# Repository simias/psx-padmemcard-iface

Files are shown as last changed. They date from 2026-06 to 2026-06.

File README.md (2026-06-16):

# ATmega4809-based interface for PlayStation Memory Cards and Controllers

This repository contains the schematics and controller code to create a simple
UART-based interface to PlayStation Memory Card and Controllers.

The design uses a simple ATmega4809 microcontroller running at 4MHz.

The PlayStation Pad/MemCard connector uses both 3.5V (for all communication
signals) and 7.5V (mainly used for DualShock rumble motors and other
power-hungry features). I think that most devices will work perfectly fine with
only the 3.5V input, but in order to be as close as possible to the real
hardware I power my board with a 7.5V that I can wire to the relevant pin of the
Pad/MemCard port, and I use a cheap off-the-shelf DC-DC module to convert that
7.5V to 3.5V which I use to power the controller.

I also send the 5V from the UART-to-USB and UPDI inputs to the DC-DC input
(through diodes) to allow powering the board from USB, but in this case this
same 5V will be sent to the Pad/MemCards instead of a true 7.5V.

A single LED is pulsed with PWM to show activity.

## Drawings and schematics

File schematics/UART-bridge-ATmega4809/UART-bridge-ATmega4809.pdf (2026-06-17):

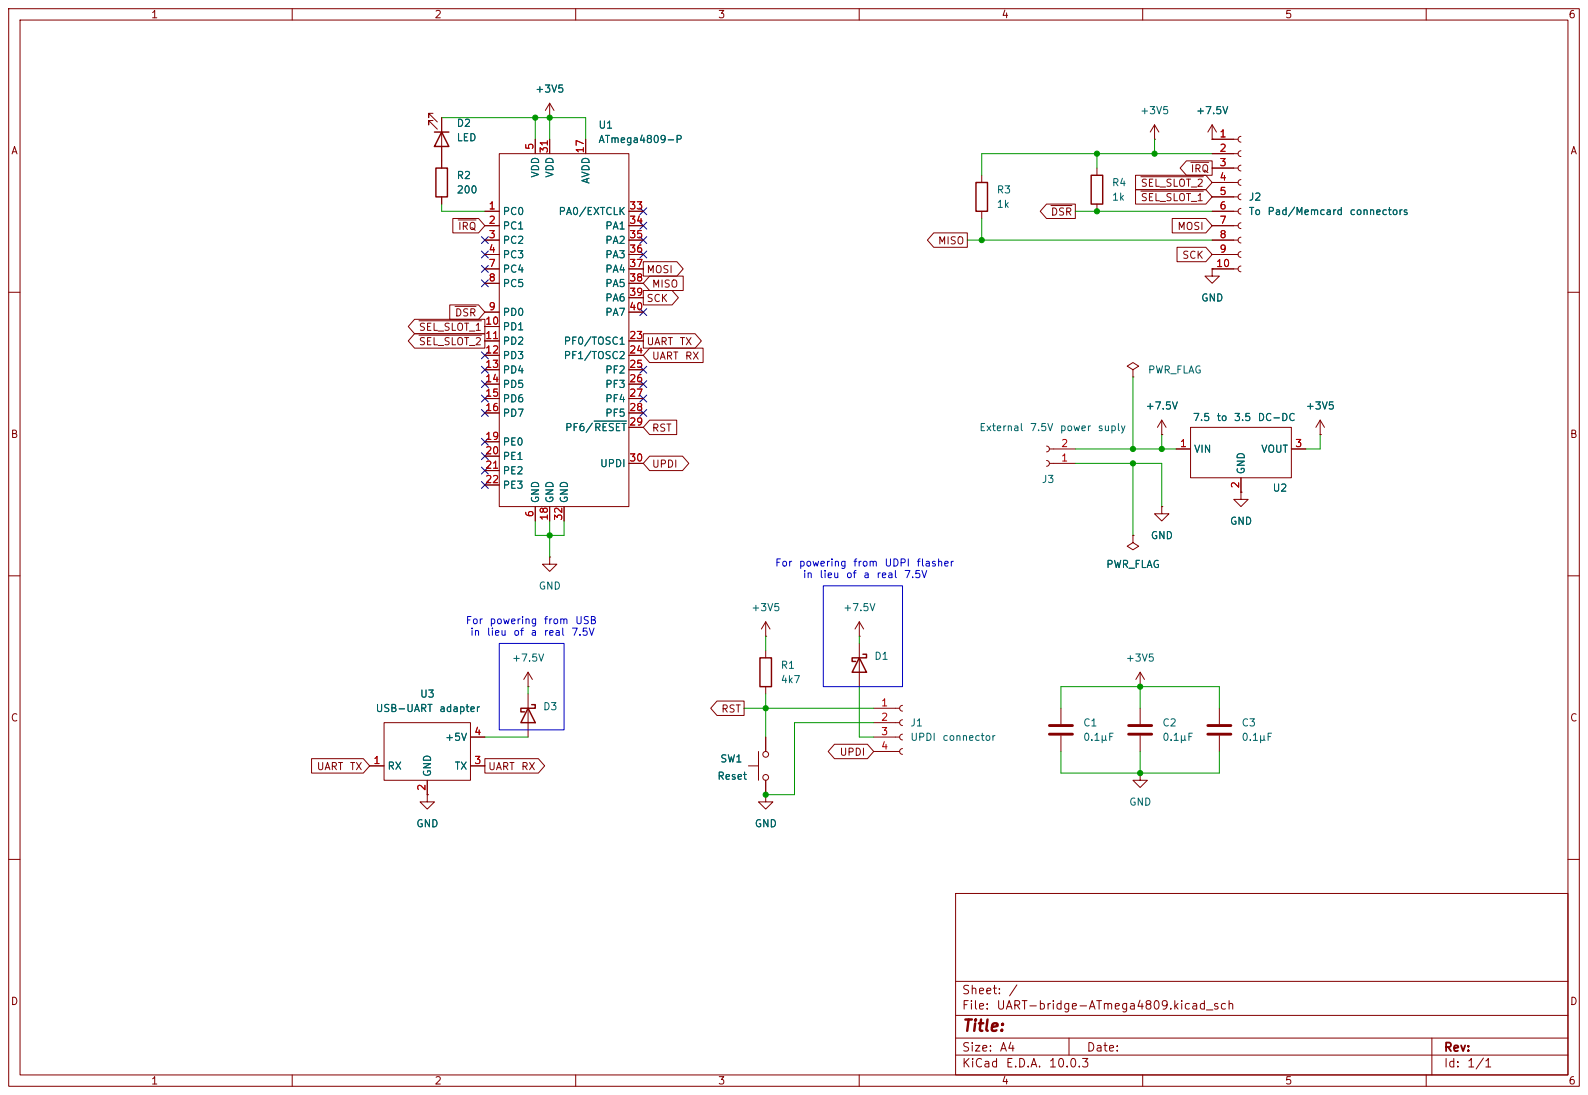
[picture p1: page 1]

in lieu of a real 7.5V U1
ATmega4809-P

6 PC4 7 PC5 8 PD0 9 PD1 10 PD2 11 PD3 12 PD4 13 PD5 14 PD6 15 PD7 16 AVDD 17 GND 18 PE0 19 PE1 20 PE2 21 PE3 22 PF0/TOSC1 23 PF1/TOSC2 24 PF2 25 PF3 26 PF4 27 PF5 28 PF6/RESET 29 UPDI 30 VDD 31 GND 32

SCK UPDI RST UART TX UART RX DSR UART TX

For powering from UDPI flasher

For powering from USB
in lieu of a real 7.5V

Size: A4 | Rev:
KiCad E.D.A. 10.0.3 | Id: 1/1

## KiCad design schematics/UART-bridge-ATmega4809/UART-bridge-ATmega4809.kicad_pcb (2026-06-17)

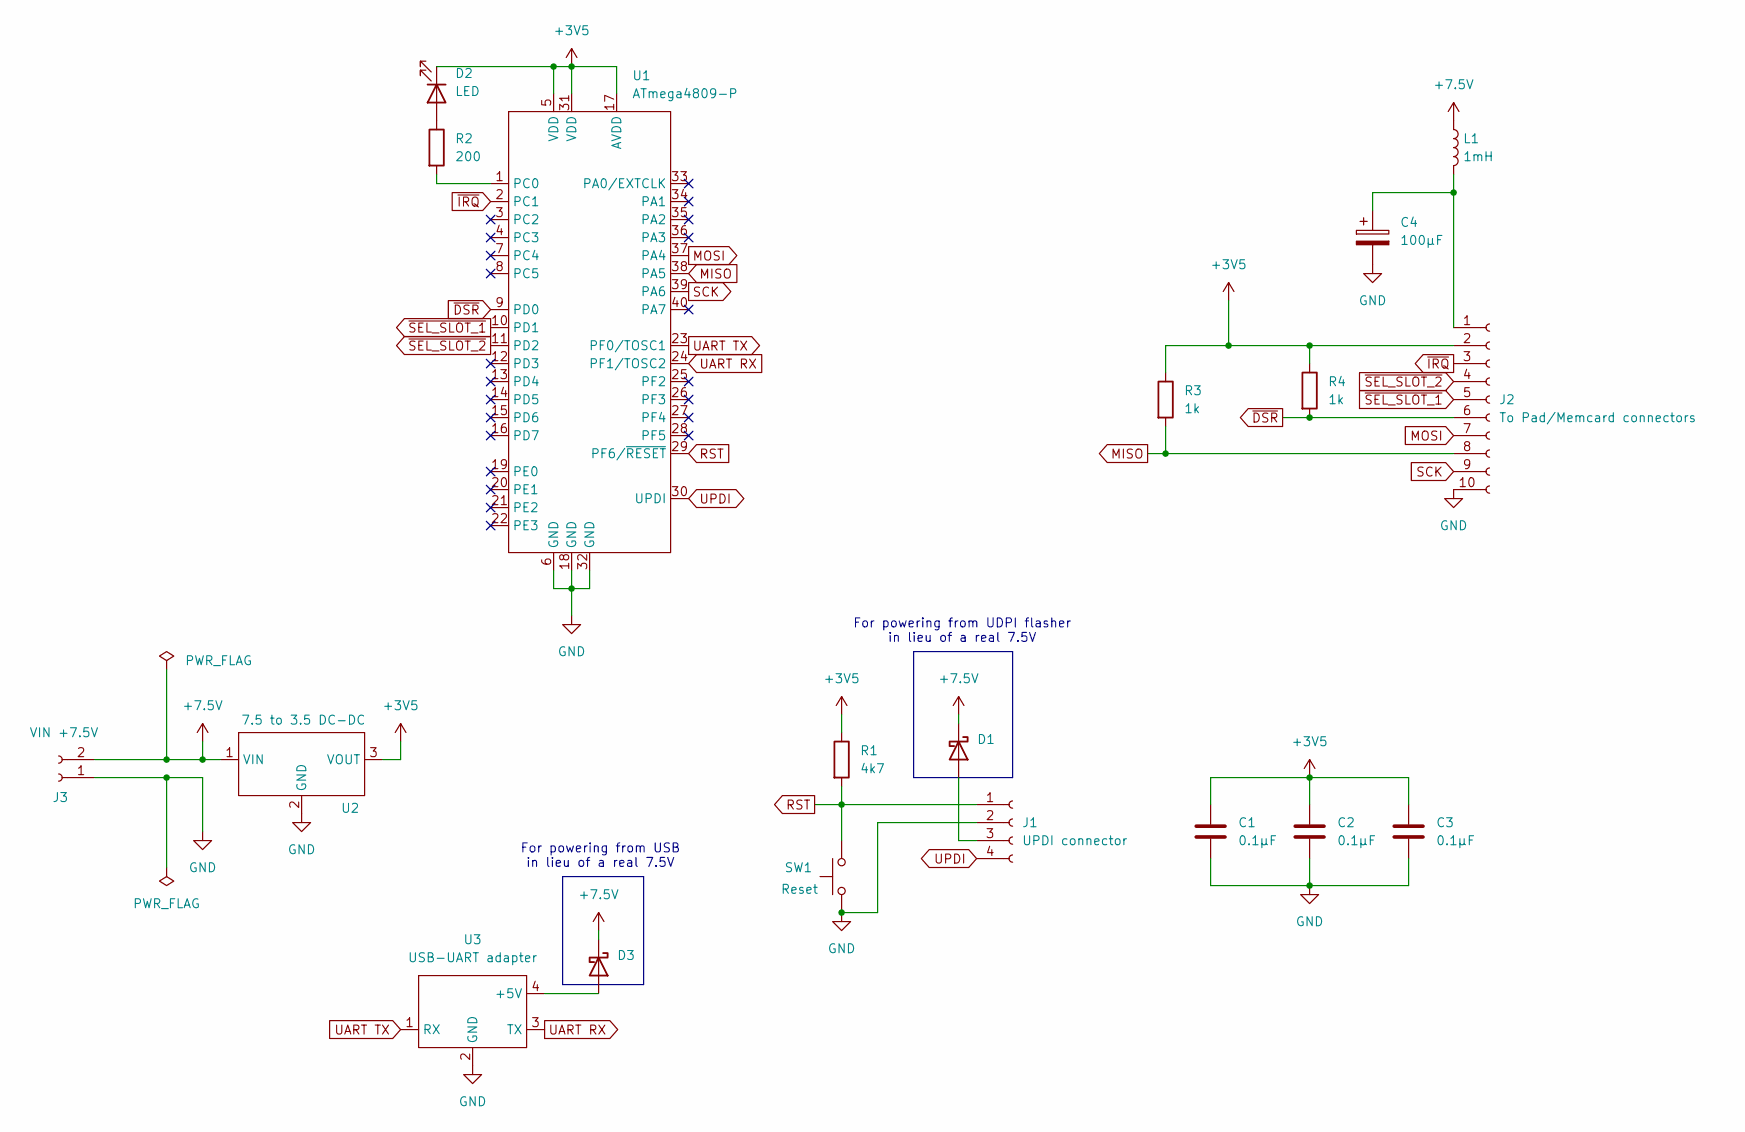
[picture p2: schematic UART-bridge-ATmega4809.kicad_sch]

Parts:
C1, C2, C3: 0.1µF; C_Disc_D5.0mm_W2.5mm_P5.00mm
C4: 100µF; C_Radial_D5.0mm_H11.0mm_P2.00mm
D1, D3: D_Schottky; D_A-405_P7.62mm_Horizontal
D2: LED; LED_D5.0mm_Clear
J1: UPDI connector; PinSocket_1x04_P2.54mm_Vertical
J2: To Pad/Memcard connectors; PinSocket_1x10_P2.54mm_Vertical
J3: VIN +7.5V; PinSocket_1x02_P2.54mm_Vertical
L1: 1mH; L_Radial_D7.0mm_P3.00mm
R1: 4k7; R_Axial_DIN0207_L6.3mm_D2.5mm_P7.62mm_Horizontal
R2: 200; R_Axial_DIN0207_L6.3mm_D2.5mm_P7.62mm_Horizontal
R3, R4: 1k; R_Axial_DIN0207_L6.3mm_D2.5mm_P7.62mm_Horizontal
SW1: Reset; SW_PUSH_6mm
U1: ATmega4809-P; DIP-40_W15.24mm_Socket
U2: 7.5 to 3.5 DC-DC; PinSocket_1x03_P2.54mm_Vertical
U3: USB-UART adapter; PinSocket_1x06_P2.54mm_Vertical

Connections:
+3V5: C1.1, C2.1, C3.1, D2.1 (K), J2.2, R1.1, R3.1, R4.1, U1.5 (VDD), U1.17 (AVDD), U1.31 (VDD), U2.3 (VOUT)
+7.5V: D1.1 (K), D3.1 (K), J3.2, L1.1, U2.1 (VIN)
GND: C1.2, C2.2, C3.2, C4.2, J1.2, J2.10, J3.1, SW1.1, U1.6 (GND), U1.18 (GND), U1.32 (GND), U2.2 (GND), U3.2 (GND)
MISO: J2.8, R3.2, U1.38 (PA5)
MOSI: J2.7, U1.37 (PA4)
unnamed: D1.2 (A), J1.3
unnamed: D2.2 (A), R2.1
unnamed: D3.2 (A), U3.4 (+5V)
unnamed: C4.1, J2.1, L1.2
unnamed: R2.2, U1.1 (PC0)
RST: J1.1, R1.2, SW1.2, U1.29 (PF6/~RESET)
SCK: J2.9, U1.39 (PA6)
UART RX: U1.24 (PF1/TOSC2), U3.3 (TX)
UART TX: U1.23 (PF0/TOSC1), U3.1 (RX)
UPDI: J1.4, U1.30 (UPDI)
~DSR: J2.6, R4.2, U1.9 (PD0)
~IRQ: J2.3, U1.2 (PC1)
~SEL_SLOT_1: J2.5, U1.10 (PD1)
~SEL_SLOT_2: J2.4, U1.11 (PD2)

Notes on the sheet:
For powering from USB in lieu of a real 7.5V
For powering from UDPI flasher in lieu of a real 7.5V

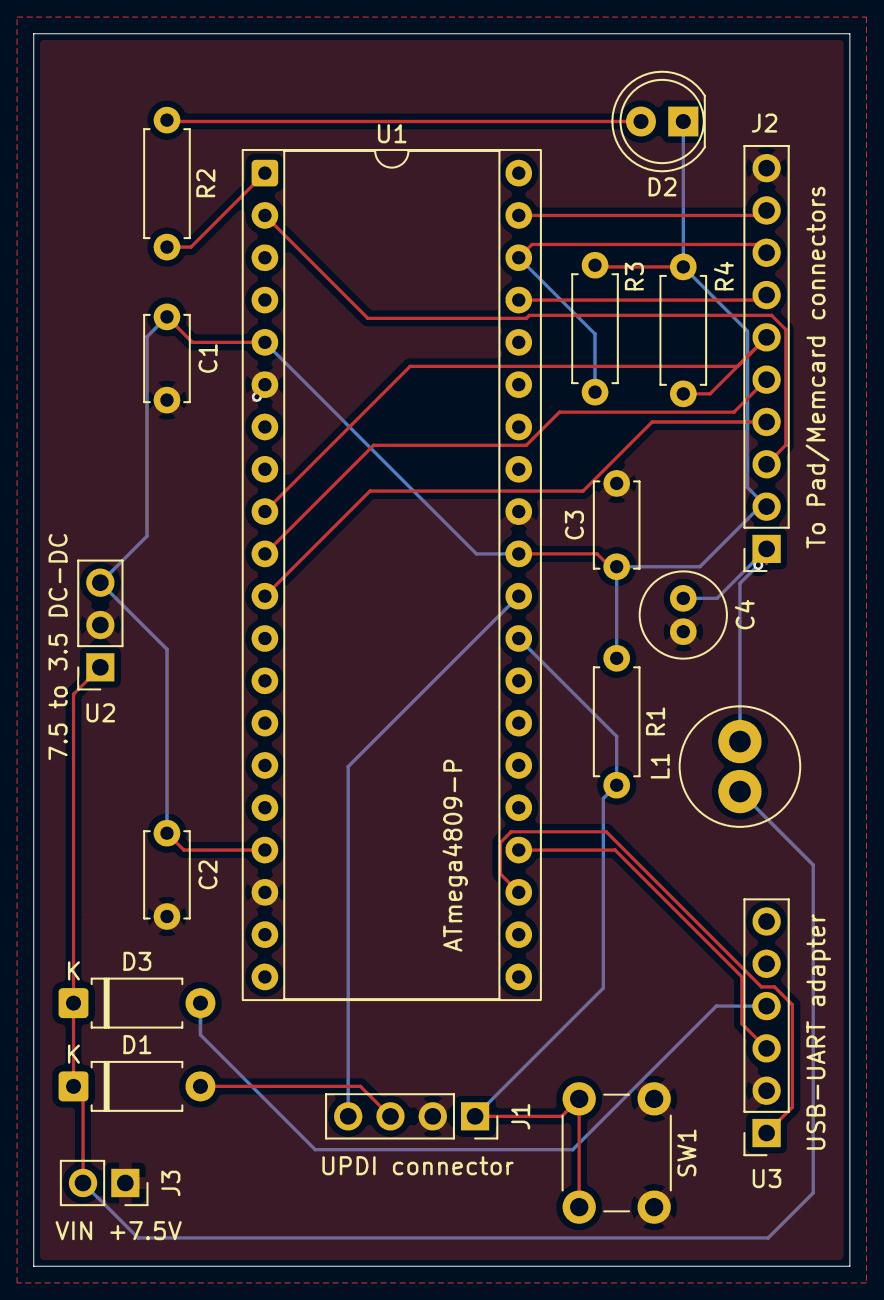
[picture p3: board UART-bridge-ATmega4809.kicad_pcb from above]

Board: 2 copper layers, 49.0 x 74.0 mm, 19 parts (0 on the bottom side), 19 nets.

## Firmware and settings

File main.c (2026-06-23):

#include <avr/interrupt.h>
#include <avr/io.h>
#include <avr/sleep.h>
#include <avr/wdt.h>
#include <stdbool.h>
#include <stdio.h>
#include <util/delay.h>

#define ARRAY_SIZE(_arr) (sizeof(_arr) / sizeof((_arr)[0]))

#define BAUD_RATE 115200
#define USART_BAUD_RATE(_br) ((F_CPU * 4 + (_br) / 2) / (_br))

enum padmem_slot {
    SLOT_1 = 1,
    SLOT_2 = 2,
};

static void spi_init(void)
{
    /* Set MOSI and CLK pins direction to output */
    PORTA.DIR |= PIN4_bm | PIN6_bm;

    /* Pull Up on MISO (warning: needs external 1kohm pull-up, in my tests this
     * internal PU is not sufficient)*/
    PORTA.PIN5CTRL = PORT_PULLUPEN_bm;

    SPI0.CTRLB = SPI_MODE_3_gc | SPI_SSD_bm;

    /* LSB first, CLK_PER / 16 */
    SPI0.CTRLA = SPI_DORD_bm | SPI_ENABLE_bm | SPI_MASTER_bm |
                 SPI_PRESC_DIV16_gc;
}

static uint8_t spi_wait_bsy(void)
{
    for (;;) {
        uint8_t flg = SPI0.INTFLAGS;

        if (flg & SPI_WRCOL_bm) {
            printf("SPI collision!");
            return 0xff;
        }

        if (flg & SPI_IF_bm) {
            return SPI0.DATA;
        }
    }
}

static uint8_t spi_exchange(uint8_t v)
{
    SPI0.DATA = v;
    return spi_wait_bsy();
}

/* Must be a power of two */
#define TX_FIFO_LEN 0x40
#define TX_FIFO_IMASK ((TX_FIFO_LEN << 1) - 1)

static volatile uint8_t uart_tx_fifo[TX_FIFO_LEN];
static volatile uint8_t uart_tx_wi = 0;
static volatile uint8_t uart_tx_ri = 0;

static bool uart_can_write(void)
{
    return USART2.STATUS & USART_DREIF_bm;
}

ISR_N(USART2_DRE_vect_num)
static void uart_tx_irq(void)
{
    uint8_t ri = uart_tx_ri;
    uint8_t wi = uart_tx_wi;

    if (ri != wi && uart_can_write()) {
        USART2.TXDATAL = uart_tx_fifo[(ri++) & (TX_FIFO_LEN - 1)];
        uart_tx_ri = ri & TX_FIFO_IMASK;
    }

    if (ri == wi) {
        /* FIFO empty, disable IRQ */
        USART2.CTRLA &= ~USART_DREIE_bm;
    }
}

static void uart_putchar(int c)
{
    uint8_t sr = SREG;
    uint8_t ri;
    uint8_t wi;

    cli();

    ri = uart_tx_ri;
    wi = uart_tx_wi;

    if (ri == wi && uart_can_write()) {
        /* FIFO is empty and UART can accept a byte, just use that */
        USART2.TXDATAL = c;
        goto done;
    }

    /* UART is busy, attempt to store in the buffer */
    while ((wi ^ TX_FIFO_LEN) == ri) {
        /* Buffer full! */
        if (!(sr & CPU_I_bm)) {
            /* Interrupts were disabled when we were called, we can't sleep, so
             * we give up. */
            goto done;
        }

        /* Wait for UART to empty */
        sei();
        sleep_cpu();
        cli();

        ri = uart_tx_ri;
        wi = uart_tx_wi;
    }

    uart_tx_fifo[(wi++) & (TX_FIFO_LEN - 1)] = c;

    uart_tx_wi = wi & TX_FIFO_IMASK;

    USART2.CTRLA |= USART_DREIE_bm;

done:
    SREG = sr;
}

static int uart_putchar_stream(char c, FILE *stream)
{
    (void)stream;

    if (c == '\n') {
        uart_putchar('\r');
    }

    uart_putchar(c);

    return c;
}

static FILE uart_stream =
    FDEV_SETUP_STREAM(uart_putchar_stream, NULL, _FDEV_SETUP_WRITE);

static void uart_tx_frame(uint8_t cmd, const uint8_t *dat, uint8_t len)
{
    uint8_t csum = cmd;
    uint8_t i;

    uart_putchar(0xa6);
    uart_putchar(cmd);

    for (i = 0; i < len; i++) {
        uint8_t b = dat[i];
        csum += b;
        uart_putchar(b);
        if (b == 0xa7) {
            /* Escape */
            uart_putchar(b);
        }
    }

    uart_putchar(0xa7);
    uart_putchar((len + 1) & 0x7f);
    uart_putchar(csum ^ 0xff);
}

static void uart_tx_nack(void)
{
    uart_tx_frame('!', NULL, 0);
}

enum uart_rx_state {
    RX_START,
    WAIT_FOR_DATA,
    WAIT_FOR_ESCAPE,
    WAIT_FOR_CSUM,
    RX_DONE,
};

static volatile enum uart_rx_state uart_st = RX_START;
static volatile uint8_t rx_buf[256];
static volatile uint8_t rx_buf_len;

ISR_N(USART2_RXC_vect_num)
static void uart_rx_irq(void)
{
    uint8_t b = USART2.RXDATAL;
    enum uart_rx_state nstate = RX_START;
    /* How many bytes to receive - 1*/
    static uint8_t csum;
    static uint8_t wi;

    switch (uart_st) {
    case RX_START:
        if (b == 0xa5) {
            wi = 0;
            csum = 0;
            nstate = WAIT_FOR_DATA;
        }
        break;

    case WAIT_FOR_DATA:
        if (b == 0xa7) {
            nstate = WAIT_FOR_ESCAPE;
        } else {
            rx_buf[wi++] = b;
            csum += b;
            nstate = WAIT_FOR_DATA;

            if (wi == 0) {
                /* Overflow */
                nstate = RX_START;
            }
        }

        break;

    case WAIT_FOR_ESCAPE:
        if (b == 0xa7) {
            /* 0xa7 0xa7 -> we want an 0xa7 */
            rx_buf[wi++] = b;
            csum += b;
            nstate = WAIT_FOR_DATA;

            if (wi == 0) {
                /* Overflow */
                nstate = RX_START;
            }
        } else if ((b >> 4) == 0xb) {
            /* 0-RLE
             *
             * We could use a more aggressive encoding allowing for even longer
             * runs, but eventually the decoding takes too long and we miss the
             * next byte. Plus the gains become really small.
             */
            uint8_t nzero = (b & 0xf) + 3;
            uint8_t wi_s = wi;

            nstate = WAIT_FOR_DATA;

            while (nzero--) {
                rx_buf[wi++] = 0;
            }

            if (wi < wi_s) {
                /* Overflow */
                nstate = RX_START;
            }
        } else if (b == (wi & 0x7f)) {
            /* End of data */
            nstate = WAIT_FOR_CSUM;
        } else {
            /* Spurious/corrupted data */
            uart_tx_nack();
            nstate = RX_START;
        }

        break;

    case WAIT_FOR_CSUM:
        if ((csum ^ 0xff) == b) {
            rx_buf_len = wi;
            nstate = RX_DONE;
        } else {
            uart_tx_nack();
        }
        break;

    case RX_DONE:
        if (wi > 0) {
            nstate = RX_DONE;
        } else {
            nstate = RX_START;
        }
        break;
    }

    if (nstate != RX_START && nstate != RX_DONE) {
        TCA0.SINGLE.CMP0BUF = 0x20;
    }

    uart_st = nstate;
}

static void uart_init(void)
{
    /* Add pull-up on RX pin for when nothing is connected */
    PORTF.PIN1CTRL = PORT_PULLUPEN_bm;

    /* PIN F1 TX*/
    PORTF.DIR |= PIN0_bm;

    USART2.BAUD = USART_BAUD_RATE(BAUD_RATE);
    USART2.CTRLA = USART_RXCIE_bm;
    USART2.CTRLB = USART_TXEN_bm | USART_RXEN_bm;

    stdout = &uart_stream;
}

static void pwm_init(void)
{
    /* LED on PC0: use PWM */
    PORTC.DIR |= PIN0_bm;

    PORTMUX.TCAROUTEA &= ~PORTMUX_TCA0_gm;
    PORTMUX.TCAROUTEA |= PORTMUX_TCA0_PORTC_gc;

    /* Period */
    TCA0.SINGLE.PER = 0xff;

    /* Duty cycle */
    TCA0.SINGLE.CMP0 = 0x10;

    TCA0.SINGLE.CTRLB = TCA_SINGLE_CMP0EN_bm | TCA_SINGLE_WGMODE_SINGLESLOPE_gc;

    /* Set divider */
    TCA0.SINGLE.CTRLA = TCA_SINGLE_CLKSEL_DIV2_gc | TCA_SINGLE_ENABLE_bm;
}

static void rtc_waitbsy(void)
{
    while (RTC.STATUS & (RTC_CTRLABUSY_bm | RTC_CNTBUSY_bm | RTC_PERBUSY_bm |
                         RTC_CMPBUSY_bm)) {
        ;
    }
}

static volatile uint8_t nticks_10ms = 0;

ISR_N(RTC_CNT_vect_num)
static void rtc_irq(void)
{
    uint8_t pwm_cmp;

    /* ACK */
    RTC.INTFLAGS = RTC_OVF_bm;

    nticks_10ms++;

    pwm_cmp = TCA0.SINGLE.CMP0BUFL;

    if (pwm_cmp > 10) {
        pwm_cmp -= 2;

        TCA0.SINGLE.CMP0BUFL = pwm_cmp;
        TCA0.SINGLE.CMP0BUFH = 0;
    }
}

static void rtc_init(void)
{
    /* We want a tic every 10ms */
    rtc_waitbsy();
    RTC.PER = (32768 + (100 >> 1)) / 100;

    rtc_waitbsy();
    RTC.CLKSEL = RTC_CLKSEL_INT32K_gc;

    /* Enable overflow IRQ */
    rtc_waitbsy();
    RTC.INTCTRL = RTC_OVF_bm;

    /* Enable RTC with no prescaling */
    rtc_waitbsy();
    RTC.CTRLA = RTC_RTCEN_bm | RTC_PRESCALER_DIV1_gc;

    rtc_waitbsy();
}

static volatile uint8_t ndsr = 0;

ISR_N(PORTD_PORT_vect_num)
static void portd_irq(void)
{
    uint8_t flags = PORTD.INTFLAGS;

    /* ACK */
    PORTD.INTFLAGS = flags;

    if (flags & PORT_INT_0_bm) {
        TCA0.SINGLE.CMP0BUFL = 0xff;
        TCA0.SINGLE.CMP0BUFH = 0;
        ndsr++;
    }
}

/* Returns true if DSR is active (that is, /DSR is at 0) */
static bool dsr(void)
{
    return !(PORTD.IN & PIN0_bm);
}

static void init(void)
{
    cli();

    /* Per datasheet:
     *
     * The 40-pin version of the ATmega4809 is using the die of the 48-pin
     * ATmega4809 but offers fewer connected pads. For this reason, the pins
     * PB[5:0] and PC[7:6] must be disabled (INPUT_DISABLE) or enable pull-ups
     * (PULLUPEN).
     */
    PORTB.PIN0CTRL &= ~PORT_ISC_gm;
    PORTB.PIN0CTRL |= PORT_ISC_INPUT_DISABLE_gc;
    PORTB.PIN1CTRL &= ~PORT_ISC_gm;
    PORTB.PIN1CTRL |= PORT_ISC_INPUT_DISABLE_gc;
    PORTB.PIN2CTRL &= ~PORT_ISC_gm;
    PORTB.PIN2CTRL |= PORT_ISC_INPUT_DISABLE_gc;
    PORTB.PIN3CTRL &= ~PORT_ISC_gm;
    PORTB.PIN3CTRL |= PORT_ISC_INPUT_DISABLE_gc;
    PORTB.PIN4CTRL &= ~PORT_ISC_gm;
    PORTB.PIN4CTRL |= PORT_ISC_INPUT_DISABLE_gc;
    PORTB.PIN5CTRL &= ~PORT_ISC_gm;
    PORTB.PIN5CTRL |= PORT_ISC_INPUT_DISABLE_gc;
    PORTC.PIN6CTRL &= ~PORT_ISC_gm;
    PORTC.PIN6CTRL |= PORT_ISC_INPUT_DISABLE_gc;
    PORTC.PIN7CTRL &= ~PORT_ISC_gm;
    PORTC.PIN7CTRL |= PORT_ISC_INPUT_DISABLE_gc;

    /* Enable prescaler with PDIV = (DIV 4). With fuse2/osccfg set to 0x01
     * that will give us a 4MHz CPU clock.
     *
     * According to the datasheet, with our 3V5 power supply the chip cannot
     * safely run at 16MHz but we could run at 10MHz if we wanted and stay
     * within the safe range. But then we have to take into account that we want
     * the SPI to run at 250kHz...
     */
    _PROTECTED_WRITE(CLKCTRL_MCLKCTRLB, CLKCTRL_PEN_bm | CLKCTRL_PDIV_4X_gc);

    uart_init();

    pwm_init();

    spi_init();

    rtc_init();

    /* /DSR: PD0, IRQ on falling edge, (warning: needs external 1kohm pull-up,
     * in my tests this internal PU is not sufficient) */
    PORTD.PIN0CTRL = PORT_ISC_FALLING_gc;

    /* /SEL1: PD1, /SEL2: PD2 */
    PORTD.DIR |= PIN1_bm | PIN2_bm;
    PORTD.OUTSET |= PIN1_bm | PIN2_bm;

    set_sleep_mode(SLEEP_MODE_IDLE);
    sleep_enable();

    /* Make sure the peripherals see stable values before we attempt to start a
     * command */
    _delay_ms(200);

    sei();

    puts("Starting up...");
}

static uint8_t run_command(enum padmem_slot slot, volatile const uint8_t *cmd,
                           uint8_t len)
{
    uint8_t ndsr_pre = ndsr;
    unsigned i;
    uint8_t b;
    uint8_t csum = 'X';

    uart_putchar(0xa6);
    uart_putchar('X');

    /* Select port */
    if (slot == SLOT_1) {
        PORTD.OUTCLR = PIN1_bm;
    } else {
        PORTD.OUTCLR = PIN2_bm;
    }
    _delay_us(30);

    /* Send the command, waiting for /DSR between each byte */
    for (i = 0; i < len; i++) {
        uint8_t tx = cmd[i];

        if (i > 0) {
            /* Wait for DSR */
            uint8_t timeout = nticks_10ms + 5;

            while (nticks_10ms != timeout && ndsr == ndsr_pre) {
                ;
            }

            if (ndsr == ndsr_pre) {
                /* Timeout while waiting for DSR */
                goto done;
            }
        }

        /* Make sure DSR is inactive before we start */
        while (dsr()) {
            ;
        }

        _delay_us(4);

        ndsr_pre = ndsr;

        b = spi_exchange(tx);

        csum += b;
        uart_putchar(b);
        if (b == 0xa7) {
            uart_putchar(b);
        }
    }

done:
    /* Deselect everything */
    PORTD.OUTSET |= PIN1_bm | PIN2_bm;

    uart_putchar(0xa7);
    uart_putchar((i + 1) & 0x7f);
    uart_putchar(csum ^ 0xff);

    _delay_us(20);

    return i;
}

int main(void)
{
    init();

    for (;;) {
        cli();
        if (uart_st != RX_DONE) {
            /* This may look race-y but it isn't: the instruction immediately
             * after SEI is guaranteed to be executed before any IRQ is handled.
             * So it's not possible for an IRQ to sneak in-between.
             */
            sei();
            sleep_cpu();
            continue;
        }
        sei();

        switch (rx_buf[0]) {
        case '?':
            /* Query interface version */
            {
                uint8_t version[] = { 1, 0, 0 };

                uart_tx_frame('?', version, ARRAY_SIZE(version));
            }
            break;
        case 'X':
            /* Send a transaction to the slot provided and return the response.
             * The transfer will stop early if we don't receive a DSR
             */
            {
                uint8_t slot;

                if (rx_buf_len < 2) {
                    uart_tx_nack();
                }

                slot = rx_buf[1];

                if (slot != SLOT_1 && slot != SLOT_2) {
                    printf("Bad slot %d\n", slot);
                    uart_tx_nack();
                }

                run_command(slot, rx_buf + 2, rx_buf_len - 2);
            }
            break;
        default:
            printf("Unknown command %x\n", rx_buf[0]);
            uart_tx_nack();
        }

        /* We're ready to accept the next command */
        uart_st = RX_START;
    }
}

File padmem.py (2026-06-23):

#!/usr/bin/env python

import argparse
import serial
import sys
import pprint
from string import printable
from time import sleep
from enum import Enum, auto
from datetime import datetime


class Slot(Enum):
    SLOT_1 = 1
    SLOT_2 = 2


class Iface:

    def __init__(self, uart_path):
        self.uart = serial.Serial(
            port=uart_path,
            baudrate=115200,
            bytesize=serial.EIGHTBITS,
            parity=serial.PARITY_NONE,
            stopbits=serial.STOPBITS_ONE,
            timeout=2,
        )

        # Flush any partial command that could be in progress
        self.uart.write(b"0xff" * 256)
        sleep(0.1)
        self.uart.read_all()

        self.verbose = False

    def send_frame(self, bytes):

        if len(bytes) == 0:
            raise ValueError("Frame is empty!")

        if len(bytes) > 255:
            raise ValueError(f"Frame length {len(bytes)} is greater than 255")

        csum = 0

        frame = bytearray(b"\xa5")

        i = 0
        while i < len(bytes):
            b = bytes[i]
            i += 1

            if b == 0:
                # We have an optimized RLE for long runs of 0
                j = i
                while j < len(bytes) and bytes[j] == 0:
                    j += 1

                nzero = min(j - i + 1, 0xF + 3)

                if nzero >= 3:
                    frame.append(0xA7)
                    frame.append(0xB0 + nzero - 3)
                    i += nzero - 1
                else:
                    frame.append(0)

            else:
                csum += b
                frame.append(b)
                if b == 0xA7:
                    # Escape
                    frame.append(b)

        # End marker
        frame.append(0xA7)
        frame.append(len(bytes) & 0x7F)
        frame.append((csum & 0xFF) ^ 0xFF)

        self.uart.write(frame)
        self.uart.flush()

    def read_or_die(self):
        b = self.uart.read(1)

        if len(b) != 1:
            raise Exception(f"Timed out while waiting for a frame...")

        return b[0]

    def receive_frame(self, expected_cmd=None):
        extra = bytearray()

        while True:
            b = self.read_or_die()

            if b == 0xA6:
                break

            extra.append(b)
            if b == ord("\n"):
                print(f"Off-band RX data: {extra}")
                extra = bytearray()

        if extra:
            print(f"Off-band RX data: {extra}")

        expected_csum = 0

        res = bytearray()
        while True:
            b = self.read_or_die()
            if b == 0xA7:
                b = self.read_or_die()
                if b != 0xA7:
                    break

            expected_csum += b
            res.append(b)

        expected_eod = len(res) & 0x7F

        if b != expected_eod:
            raise Exception(f"Invalid end marker, expected {expected_eod} got {b}")

        expected_csum = (expected_csum & 0xFF) ^ 0xFF

        csum = self.read_or_die()

        if csum != expected_csum:
            raise Exception(f"Invalid checksum, expected {expected_csum} got {csum}")

        if expected_cmd:
            if res[0 : len(expected_cmd)] != expected_cmd:
                raise Exception(f"Unexpected frame, wanted {expected_cmd} got {res}")

            return res[len(expected_cmd) :]

        return res

    def exchange_with_slot(self, slot, bytes):
        cmd = bytearray(b"X")
        cmd.append(slot.value)
        cmd += bytes

        if self.verbose:
            print(red(f"Slot {slot.value} TX:"))
            printbytes(bytes)

        self.send_frame(cmd)
        rx = iface.receive_frame(b"X")

        if self.verbose:
            print(green(f"Slot {slot.value} RX:"))
            printbytes(rx)

        return rx


def col(col, s):
    return f"\033[{col}m{s}\033[00m"


def red(s):
    return col(91, s)


def green(s):
    return col(92, s)


def purple(s):
    return col(95, s)


def printbytes(bytes, base_addr=0):
    for c in range(0, len(bytes), 16):
        bb = bytes[c : c + 16]

        buf = f"{base_addr + c: 8x}: "

        for i, b in enumerate(bb):
            if i != 0:
                buf += " "
            buf += f"{b:02x}"

        print(purple(buf))

        buf = f"          "
        for i, b in enumerate(bb):
            if i != 0:
                buf += " "
            c = chr(b)

            if c in printable:
                if c == "\n":
                    buf += "\\n"
                elif c == "\r":
                    buf += "\\r"
                elif c == "\t":
                    buf += "\\t"
                elif c == "\f":
                    buf += "\\f"
                elif c == "\v":
                    buf += "\\v"
                else:
                    buf += c + " "
            else:
                buf += " ."

        print(purple(buf))
    print(purple(f"{base_addr + len(bytes): 8x}: "))


def do_list(iface, args):
    slot = Slot(args.slot)

    r = iface.exchange_with_slot(slot, b"\x01\x42\x00\x00\x00")
    if len(r) == 5 and r[1] == 0x41 and r[2] == 0x5A:
        print(f"Slot {slot.value}: GamePad detected")
    else:
        print(f"Slot {slot.value}: No GamePad")

    r = iface.exchange_with_slot(slot, b"\x81\x52\x00\x00")
    if len(r) == 4 and r[2] == 0x5A and r[3] == 0x5D:
        print(f"Slot {slot.value}: Memory Card detected")
    else:
        print(f"Slot {slot.value}: No Memory Card")


def do_mcdump(iface, args):
    slot = Slot(args.slot)

    read_cmd = bytearray(12 + 128)
    read_cmd[0] = 0x81
    read_cmd[1] = 0x52

    f = None

    for page in range(0, 0x400):
        print(f"\r{page + 1} / {0x400}", end="")
        page_hi = page >> 8
        page_lo = page & 0xFF

        read_cmd[4] = page_hi
        read_cmd[5] = page_lo

        r = iface.exchange_with_slot(slot, read_cmd)
        if (
            len(r) != len(read_cmd)
            or r[2] != 0x5A
            or r[3] != 0x5D
            or r[6] != 0x5C
            or r[7] != 0x5D
            or r[8] != page_hi
            or r[9] != page_lo
            or r[139] != 0x47
        ):
            print(f"\nInvalid Memory Card response at page {page}")
            printbytes(r)
            return False

        data = r[10:138]

        expected_xsum = page_hi ^ page_lo
        for b in data:
            expected_xsum ^= b

        csum = r[138]

        if csum != expected_xsum:
            print(f"\nInvalid checksum at page {page}")
            printbytes(r)
            return False

        if f is None:
            f = open(args.output, "bw")

        f.write(data)
        f.flush()

    print()
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

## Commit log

2026-06-13 UART OK
2026-06-14 Added PWM code
2026-06-15 Use CMP0BUF instead of CMP0 for PWM updates to avoid glitches
    [main.c]
2026-06-15 Implement SPI interface
2026-06-16 Added schematics and README.md
    [UART-bridge-ATmega4809.kicad_pcb, UART-bridge-ATmega4809.kicad_sch]
2026-06-16 Added UART RX handling
2026-06-17 Tweak schematics, add IRQ pin for future-proofing
    [UART-bridge-ATmega4809.kicad_sch]
2026-06-17 Design PCB prototype
    [UART-bridge-ATmega4809.kicad_pcb, UART-bridge-ATmega4809.kicad_sch]
2026-06-18 Implement padmem.py, controller probe OK
2026-06-19 Implement device listing
2026-06-19 Bugfix, MC dump OK
    [main.c, padmem.py]
2026-06-20 Make UART TX async
2026-06-20 Add missing newline in mcdump
    [padmem.py]
2026-06-20 Move slot selection to the top command
2026-06-21 Implement RLE encoding to speed up UART commands
2026-06-21 Send NACK on CSUM errors
    [main.c]
2026-06-23 Allow printing with IRQ disabled
